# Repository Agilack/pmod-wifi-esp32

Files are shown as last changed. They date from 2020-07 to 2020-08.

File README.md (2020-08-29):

PMOD Wifi ESP32
===============

This project is a PMOD module that allow to add a wireless wifi interface to a
project.

CAD source
----------

This board has been designed using KiCad EDA (version 5). All sources files
(schematics, routing, ...) are available into the `prj-kicad` folder. You can
re-use this design under terms of the Creative Commons ShareAlike license
(CC BY-SA)

<table>
<tr>
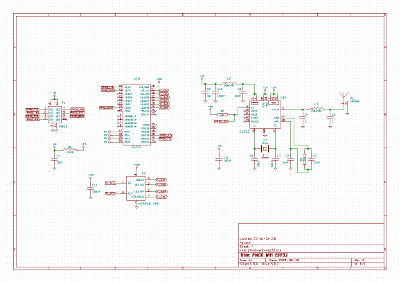
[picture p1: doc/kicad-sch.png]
KiCad Schematics
<td></td>
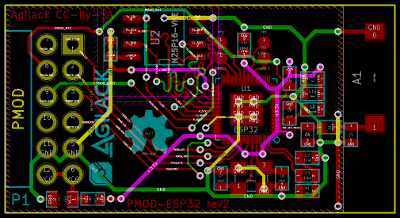
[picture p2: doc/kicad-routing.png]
KiCad routing
<td></td>
</tr>
<tr>
<td>Fig1: Preview of the KiCad schematics</td>
<td>Fig2: Preview of the KiCad routing</td>
</tr>
</table>

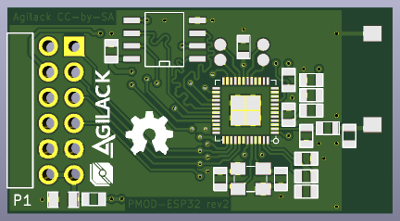
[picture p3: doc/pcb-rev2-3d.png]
PCB 3D Preview


Previous version (rev1)
-----------------------

A major hardware bug into external flash memory routing have been found into
previous version. The rev1 must be considered unusable. More informations
about this bug is available into history (see tag `rev1`)

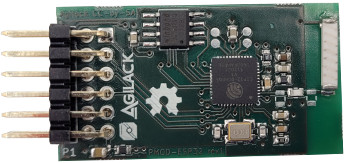
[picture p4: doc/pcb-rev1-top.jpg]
PCB rev 1


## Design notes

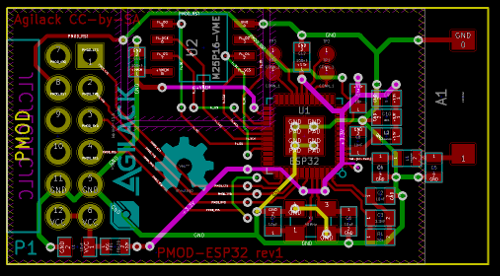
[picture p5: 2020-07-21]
doc/kicad-routing-rev1.png

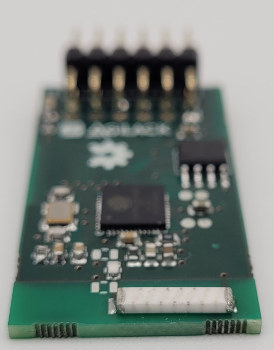
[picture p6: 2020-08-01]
doc/pcb-antenna.jpg

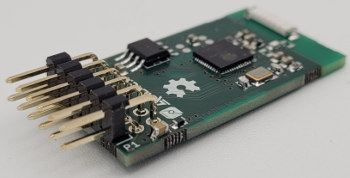
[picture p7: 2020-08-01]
doc/pcb-connector.jpg

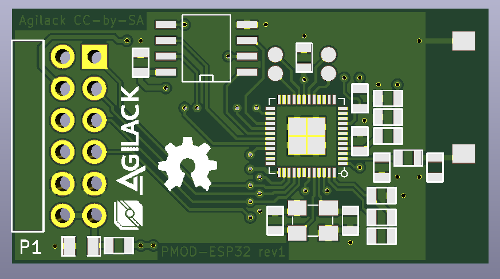
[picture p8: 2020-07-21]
doc/pcb-rev1-3d.png

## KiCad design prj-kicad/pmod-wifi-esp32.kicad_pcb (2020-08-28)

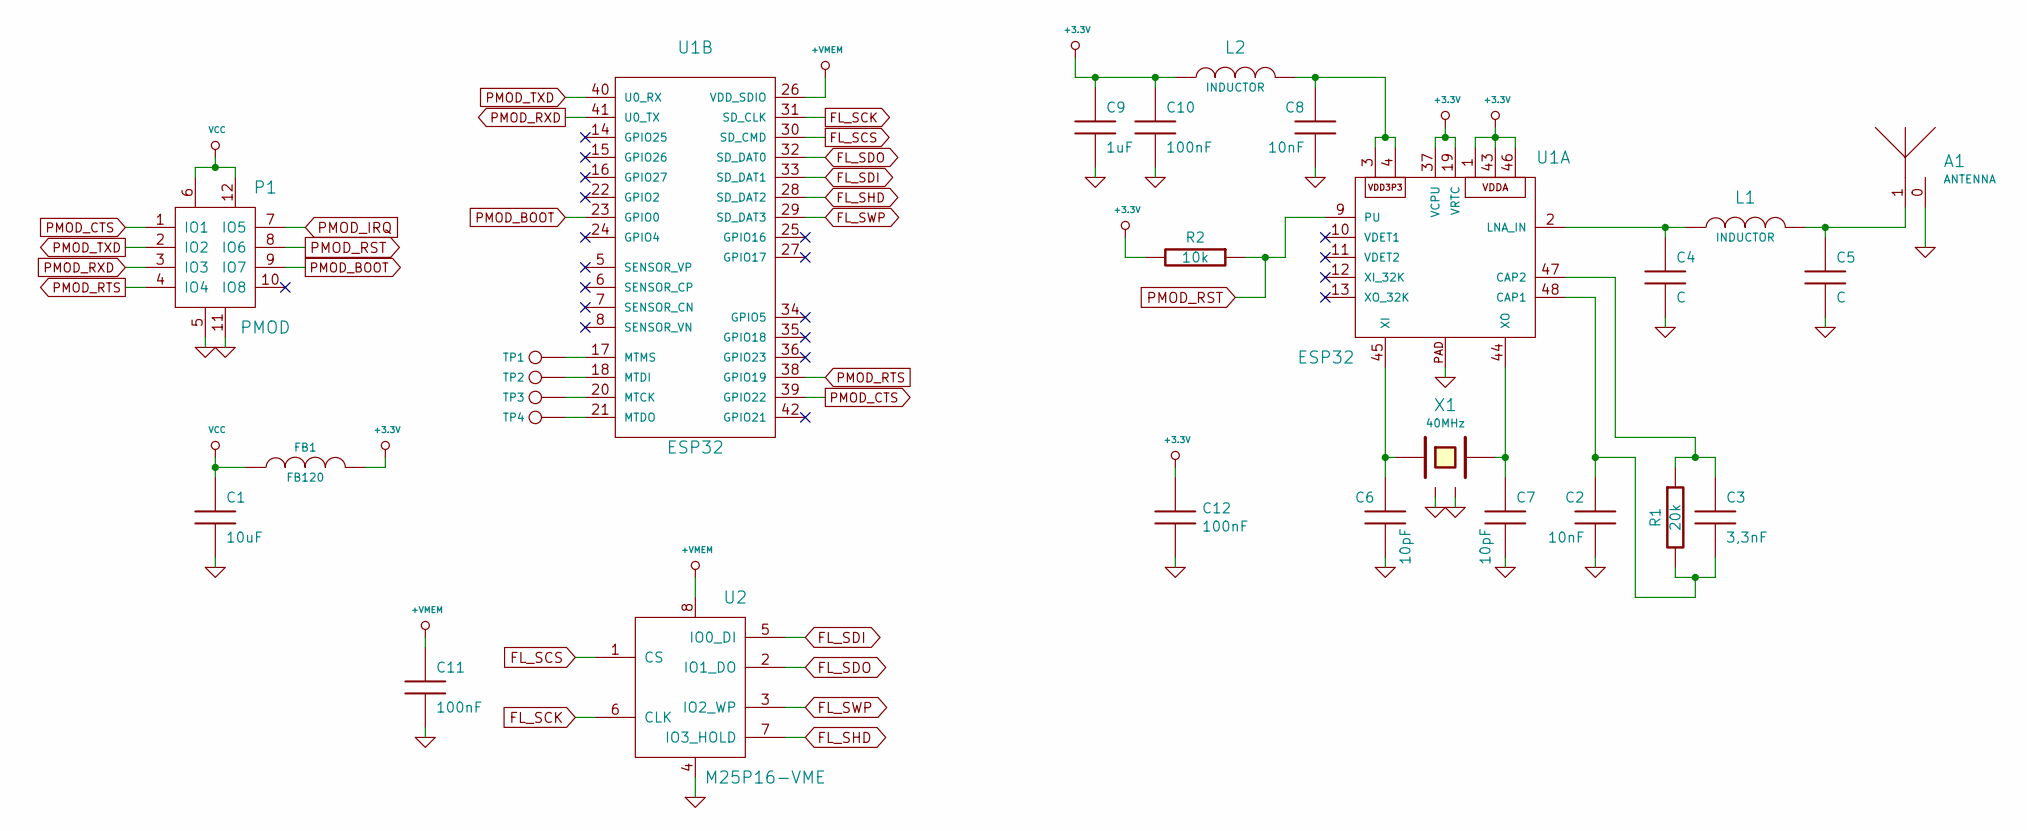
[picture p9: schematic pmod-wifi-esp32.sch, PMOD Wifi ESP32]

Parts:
A1: ANTENNA; ANT_7488910245
C1: 10uF; SMD0805
C2, C8: 10nF; SMD0603
C3: 3,3nF; SMD0603
C4, C5: C; SMD0603
C6, C7: 10pF; SMD0603
C9: 1uF; SMD0603
C10, C11, C12: 100nF; SMD0603
FB1: FB120; SMD0603
L1, L2: INDUCTOR; SMD0603
P1: PMOD; CONN_PMOD-Male
R1: 20k; SMD0603
R2: 10k; SMD0603
TP1, TP2, TP3, TP4: CONN_1; TP_SMD
U1: ESP32; QFN48-04
U2: M25P16-VME; SOIC-8
X1: 40MHz; Q_3.2x2.5

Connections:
+3.3V: C9.1, C10.1, C12.1, FB1.2, L2.1, R2.2, U1.1, U1.19 (VRTC), U1.37 (VCPU), U1.43, U1.46
+VMEM: C11.1, U1.26 (VDD_SDIO), U2.8
FL_SCK: U1.31 (SD_CLK), U2.6 (CLK)
FL_SCS: U1.30 (SD_CMD), U2.1 (CS)
FL_SDI: U1.33 (SD_DAT1), U2.5 (IO0_DI)
FL_SDO: U1.32 (SD_DAT0), U2.2 (IO1_DO)
FL_SHD: U1.28 (SD_DAT2), U2.7 (IO3_HOLD)
FL_SWP: U1.29 (SD_DAT3), U2.3 (IO2_WP)
GND: A1.0, C1.2, C2.2, C4.2, C5.2, C6.2, C7.2, C8.2, C9.2, C10.2, C11.2, C12.2, P1.5, P1.11, U1.PAD, U2.4, X1.2, X1.4
unnamed: A1.1, C5.1, L1.2
unnamed: C2.1, C3.2, R1.2, U1.48 (CAP1)
unnamed: C3.1, R1.1, U1.47 (CAP2)
unnamed: C4.1, L1.1, U1.2 (LNA_IN)
unnamed: C6.1, U1.45 (XI), X1.3
unnamed: C7.1, U1.44 (XO), X1.1
unnamed: C8.1, L2.2, U1.3, U1.4
unnamed: TP1.1, U1.17 (MTMS)
unnamed: TP2.1, U1.18 (MTDI)
unnamed: TP3.1, U1.20 (MTCK)
unnamed: TP4.1, U1.21 (MTDO)
PMOD_BOOT: P1.9 (IO7), U1.23 (GPIO0)
PMOD_CTS: P1.1 (IO1), U1.39 (GPIO22)
PMOD_IRQ: P1.7 (IO5)
PMOD_RST: P1.8 (IO6), R2.1, U1.9 (PU)
PMOD_RTS: P1.4 (IO4), U1.38 (GPIO19)
PMOD_RXD: P1.3 (IO3), U1.41 (U0_TX)
PMOD_TXD: P1.2 (IO2), U1.40 (U0_RX)
VCC: C1.1, FB1.1, P1.6, P1.12

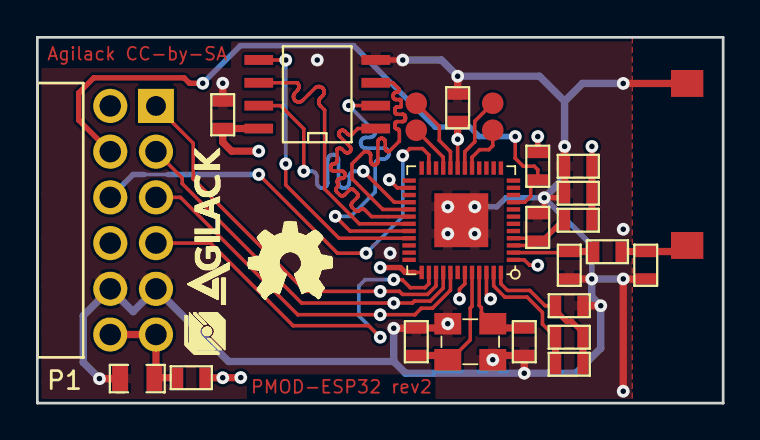
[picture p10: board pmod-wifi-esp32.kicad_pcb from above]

Board: 4 copper layers, 38.1 x 20.3 mm, 28 parts (0 on the bottom side), 27 nets.

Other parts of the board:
agilack-11.5: 450px; logo-agilack-11.5
ohw_logo: VAL**; logo-ohw

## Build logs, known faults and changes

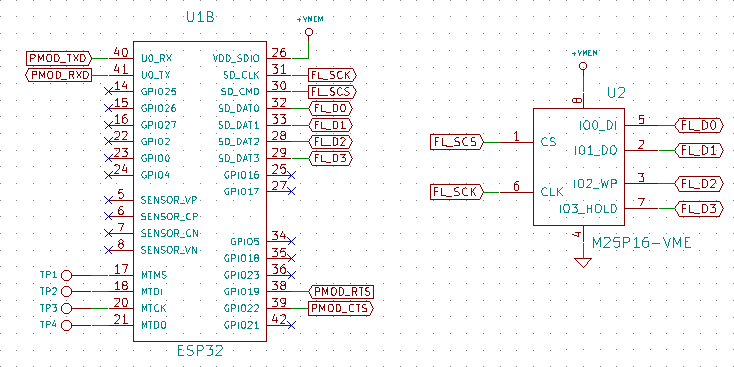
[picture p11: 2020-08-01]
doc/bug-rev1-flash.png

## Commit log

2020-07-20 = Create kicad project and draw schematics
    [pmod-wifi-esp32.kicad_pcb, pmod-wifi-esp32.sch]
2020-07-21 = ADD: PCB routing
    [pmod-wifi-esp32.kicad_pcb, pmod-wifi-esp32.sch]
2020-07-21 = ADD: Generate production files
    [pmod-wifi-esp32-B.Cu.gbr, pmod-wifi-esp32-B.Mask.gbr, pmod-wifi-esp32-B.Paste.gbr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]
2020-08-01 = ADD: Insert picture of the PCB rev1. Add note about major hardware bug
2020-08-28 = UPD: Fix bug of flash memory ios ; add a signal to control "boot" pin from pmod
    [pmod-wifi-esp32.kicad_pcb, pmod-wifi-esp32.sch]
2020-08-29 = ADD: Generate production files for rev2
    [pmod-wifi-esp32-B.Cu.gbr, pmod-wifi-esp32-B.Mask.gbr, pmod-wifi-esp32-B.Paste.gbr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]

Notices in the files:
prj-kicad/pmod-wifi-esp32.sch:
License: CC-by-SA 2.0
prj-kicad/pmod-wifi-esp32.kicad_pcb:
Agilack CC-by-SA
